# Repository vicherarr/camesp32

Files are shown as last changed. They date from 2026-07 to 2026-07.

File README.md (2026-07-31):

# 🛡️ ESP32-S3-CAM Moto Remote Vision & Security System

Un sistema de videovigilancia e IoT de bajo consumo compuesto por un **Firmware nativo en Rust para ESP32-S3-CAM** y una **Aplicación Móvil Android nativa en Kotlin con Jetpack Compose**.

---

## 📚 Documentación y Manuales Oficiales

Para consultar la información detallada del proyecto, accede a los manuales específicos ubicados en la carpeta [`docs/`](file:///home/victor/develop/iot/camesp32/docs):

- 📖 [**Manual del Dispositivo (Hardware, Leds, PIN 001989 y Operación)**](file:///home/victor/develop/iot/camesp32/docs/MANUAL_DISPOSITIVO.md)
- 📱 [**Manual de la Aplicación Android (Instalación, Pestañas y Transiciones)**](file:///home/victor/develop/iot/camesp32/docs/MANUAL_APP_ANDROID.md)
- 🏗️ [**Manual Técnico de Desarrollo (Desglose Completo de Código Rust y Kotlin)**](file:///home/victor/develop/iot/camesp32/docs/MANUAL_DESARROLLO_TECNICO.md)

---

## 📐 Arquitectura General del Sistema

El sistema utiliza un esquema **Híbrido de Bajo Consumo (BLE + WiFi Bajo Demanda)**:

```mermaid
graph TD
    A["Batería Moto / Powerbank 5V"] -->|5V / GND| B["ESP32-S3-CAM"]
    C["Radar RCWL-0516"] -->|GPIO14 ext0 wakeup| B

    subgraph ESP ["ESP32-S3 Firmware (Rust)"]
        B --> M{"¿Estado Alarma?"}
        M -->|Desarmado: Inicio/Ajustes| BLE["Bluetooth Low Energy (NimBLE)<br/>PIN 001989 · Bajo Consumo"]
        M -->|Desarmado: En Vivo/Galería| WIFI["WiFi Access Point (MIWIFI)<br/>Servidor HTTP REST"]
        M -->|Armado| DS["Deep Sleep (~µA)"]
        DS -->|Movimiento GPIO14| REC["Graba clip MJPEG-AVI a SD"]
        REC --> WIN["Ventana WiFi (~45s)<br/>para DESARMAR"]
        WIN --> DS
    end

    subgraph APP ["App Android CamEspDroid (Kotlin)"]
        K["App Android"] <-->|Control BLE / PIN 001989| BLE
        K <-->|Visión En Vivo & Galería AVI| WIFI
    end
```

---

## ⚡ Aspectos Clave del Sistema

1. **Bluetooth Low Energy (BLE) Always-On (Bajo Consumo):**
   - El canal principal de control en standby utiliza el stack NimBLE con emparejamiento por **PIN seguro `001989`** guardado en NVS (Bonding).
   - Permite armar/desarmar la alarma, conocer el estado del sensor y sincronizar la hora sin consumir batería.

2. **WiFi Bajo Demanda (Transición Implícita):**
   - El WiFi **solo se enciende cuando entras a la pestaña En Vivo o Galería** de la app.
   - La app muestra una **pantalla de progreso con cuenta atrás de 8 segundos** mientras realiza la vinculación local.
   - Al volver a la pestaña Inicio o Ajustes, el WiFi se apaga automáticamente y la radio vuelve a modo BLE.

3. **Optimizaciones de Memoria RAM:**
   - El firmware ejecuta `ble::shutdown()` liberando ~50 KB de RAM antes de levantar el WiFi para garantizar el funcionamiento fluido de la cámara y el servidor HTTP.

4. **Grabación de Vídeo MJPEG-AVI en SD:**
   - En modo armado, el radar despierta al procesador en milisegundos y graba clips `.AVI` completos con cabeceras RIFF y parcheado dinámico de FPS reales medidos.

5. **Reproductor AVI Integrado en la App Android:**
   - La app Android incluye un reproductor binario nativo escrito en Kotlin (`MjpegAviPlayer.kt`) que decodifica y reproduce los fotogramas del vídeo directamente sin depender de reproductores externos como VLC.

---

## 🚦 Leyenda de Colores del LED RGB (GPIO48)

| Estado | Color | Patrón | Significado |
| :--- | :--- | :--- | :--- |
| **Arrancando** | 🔴 rojo | fijo | Inicializando periféricos y hardware |
| **Standby Desarmado**| 🟢 verde | pulso | Esperando en bajo consumo |
| **Conectado BLE** | 🩵 cian | intercalado (1s) | App vinculada por Bluetooth |
| **Conectado WiFi** | 💛 amarillo | intercalado (1s) | Transmitiendo vídeo / galería por WiFi |
| **Ventana Armada** | 🔵 azul | parpadeo | Ventana abierta tras despertar para desarmar |
| **Grabando Vídeo** | 🟣 magenta | fijo | Grabando clip MJPEG-AVI por presencia |
| **Deep Sleep** | ⚫ apagado | — | Bajo consumo activo (~µA) |
| **Error Crítico** | 🔴 rojo | parpadeo rápido | Fallo de tarjeta MicroSD o cámara |

---

## ⚙️ Estructura del Repositorio

- [`esp32_cam_sec/`](file:///home/victor/develop/iot/camesp32/esp32_cam_sec): Proyecto completo de Firmware en Rust (ESP-IDF v5.2, NimBLE, RMT, VFS SDMMC).
- [`camesp32android/`](file:///home/victor/develop/iot/camesp32/camesp32android): Proyecto de la Aplicación Móvil Android en Kotlin (Jetpack Compose, MVVM, OkHttp, ConnectivityManager).
- [`carcasa_3d/`](file:///home/victor/develop/iot/camesp32/carcasa_3d): Modelos 3D y archivos CAD (.STEP, .STL, .FCStd) para la carcasa protectora.
- [`docs/`](file:///home/victor/develop/iot/camesp32/docs): Manuales completos del dispositivo, de la app y del desarrollo técnico.

---

## 📄 Licencia

Este proyecto está distribuido bajo la licencia MIT. Desarrollado para videovigilancia IoT de alto rendimiento y bajo consumo.

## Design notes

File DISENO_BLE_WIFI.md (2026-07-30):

# Diseño híbrido BLE + WiFi (cámara de moto)

> Caso de uso: cámara de seguridad para **moto**, se aparca lejos de casa (sin WiFi propia),
> uso en **proximidad**. Alimentación por powerbank. Ver decisiones tomadas al final.

## Principio
- **BLE = control** (siempre disponible en proximidad, ~1 mA en light-sleep): armar, desarmar,
  estado, poner la hora, encender/apagar WiFi.
- **WiFi AP = media bajo demanda** (en vivo, galería, clips): se enciende solo cuando se pide,
  y la app se conecta con **enlace local** (Android `WifiNetworkSpecifier`) para no cambiar la
  WiFi normal del móvil ni memorizar la red. Se apaga al salir.
- `alarm_armed` (NVS) solo decide **si el movimiento graba**. No hay reinicio al armar/desarmar
  (light-sleep conserva la RAM → cambio en vivo).

## Runtime del firmware (unificado)
```
BOOT → carga NVS (alarm_armed, ap_ssid/pass, pin) → arranca BLE (advertising + GATT)
       → configura PM (automatic light sleep) + wake por GPIO14 (movimiento)
LOOP (dirigido por eventos, light-sleep entre medias ~1mA):
  · Movimiento (GPIO14):
      - si armed: init cámara → grabar clip AVI a SD (con hora) → deinit cámara
      - si desarmado: solo marca estado/notifica
  · Comando BLE:
      - arm/disarm → set NVS alarm_armed (en vivo)
      - set-time(epoch) → fija RTC
      - wifi-on → levanta AP + servidor HTTP; notifica IP por BLE; lock anti-sleep
      - wifi-off (o timeout) → baja WiFi; vuelve a light-sleep
  · Durante grabación o WiFi-AP activo: PM lock (no light-sleep). Resto: light-sleep.
```

## GATT (servicio "Alarm Control")
- Service UUID: `a1b2c3d4-1111-4a5b-8c6d-000000000001` (provisional).
- **Estado** (read + notify): bytes `[armed, motion, wifi_on, ip(4)]`.
- **Comando** (write, con auth por PIN/bonding): 1 byte + args
  - `0x00` desarmar · `0x01` armar · `0x02` wifi-on · `0x03` wifi-off · `0x04` set-time (+8 bytes epoch ms)
- Nombre BLE: `CAMSEC-xxxx` (sufijo del MAC). Bonding con PIN.

## Ficheros y hora
- **FATFS LFN activado** (`CONFIG_FATFS_LONG_FILENAMES`) → nombres largos.
- Clip: `AAAAMMDD-HHMMSS.avi` si hay hora; si no, `CLIP0001.avi`.
- La hora la fija el móvil por BLE al conectar; el RTC la mantiene en light-sleep.

## App Android (pantallas)
- **Inicio**: estado por BLE (armado/desarmado, conectado, movimiento) + botón Armar/Desarmar
  (BLE). Indicadores BLE ● / WiFi ●.
- **En Vivo**: botón "encender cámara" → BLE wifi-on → la app abre el stream por la IP con
  enlace local. Solo con WiFi.
- **Galería**: media por WiFi bajo demanda. Fotos con Coil; **vídeos con reproductor MJPEG in-app**
  (parsea el AVI, extrae los JPEG `00dc`, play/pausa).
- **Ajustes**: emparejar BLE (elegir dispositivo + PIN), SSID/clave del AP de la placa, hora.
  Sin IP manual.
- Capa nueva: `BleManager` (escaneo/bond/notify/write) + uso de `WifiNetworkSpecifier` para la media.
- Permisos: `BLUETOOTH_SCAN`, `BLUETOOTH_CONNECT`, y los de WiFi/red ya presentes.

## Seguridad
- BLE: bonding con **PIN** (solo el móvil emparejado desarma).
- HTTP (media): añadir **auth básica** (usuario/clave) al servidor.

## Fases de implementación
1. **Firmware BLE core**: esp32-nimble, servicio GATT, arm/disarm/set-time; verificable con
   `bluetoothctl`. (Sin tocar aún el sleep.)
2. **Runtime unificado + PM light-sleep** (~1 mA) + WiFi AP on-demand + LFN/hora.
3. **App**: BLE + WifiNetworkSpecifier + reproductor de vídeo + rediseño de pantallas.
4. Auth HTTP + pulido + pruebas en placa.

## Decisiones tomadas (2026-07-30)
- WiFi: **AP bajo demanda + enlace local** (no STA; se aparca sin WiFi de casa).
- Vídeo: **reproductor in-app**.
- BLE: **emparejado con PIN**.
- Alimentación: powerbank (el ~1 mA del BLE en light-sleep es aceptable).

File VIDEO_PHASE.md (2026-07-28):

# Fase Futura (NO prioritaria): Grabación de Vídeo

> Análisis de viabilidad realizado el 2026-07-28 con datos reales de la webcam elegida
> (**Microdia / Sonix `0c45:2006`**, MJPEG). **Prioridad actual: FOTOS**, según lo ya definido.
> Este documento queda como referencia para cuando se aborde el vídeo.

## Resumen ejecutivo

Es viable grabar vídeo en la ESP32-S3-CAM, **pero solo como Motion-JPEG (MJPEG) en contenedor AVI**.
El ESP32-S3 **no tiene codificador de vídeo por hardware** (ni H.264/H.265; eso solo lo trae el
ESP32-P4), así que "vídeo" = secuencia de fotogramas JPEG guardados en un `.avi`.

**Objetivo realista y fiable: clips AVI-MJPEG de 640×480 a ~10 fps, grabados por evento de
movimiento** (no grabación continua). Sin audio (la cámara no tiene micrófono UAC).

## Datos medidos (frames MJPEG reales de la cámara)

| Resolución | Peso real por frame |
| :--- | :--- |
| 640×480 | **~52 KB** |
| 1280×720 | ~131 KB |

## Los dos cuellos de botella

### 1. Ancho de banda USB — Full-Speed
El USB del ESP32-S3 es **solo Full-Speed** (~780 KB/s útiles con la alt-setting isócrona de 800 B/frame).
- 640×480 → 780 ÷ 52 ≈ **15 fps máximo**.
- 1280×720 → ~6 fps (descartado para vídeo fluido).

### 2. Escritura en tarjeta SD — modo 1-bit (cuello más serio)
El firmware monta la SD en **1-bit** (`src/storage.rs`: solo D0, `CLK=39 / CMD=38 / D0=40`, `width=1`).
Escritura sostenida real ≈ **0.5–1.5 MB/s**.
- 640×480 @ 15 fps = 780 KB/s → **al límite** (riesgo de frames perdidos).
- 640×480 @ 10 fps = 520 KB/s → **seguro**.

Tamaño de archivo: 640×480 @ 10 fps ≈ **1.8 GB/hora**. FAT32 limita a **4 GB por archivo**
→ hay que **trocear en clips** (por tiempo o por evento de movimiento).

## Cómo implementarlo (cuando toque)

1. **Hilo de captura USB** (el mismo driver UVC de la fase de foto) volcando frames a un
   **ring-buffer en PSRAM** (~2–4 MB; la placa tiene PSRAM octal) para desacoplar captura de escritura.
2. **Hilo escritor** que vacía el ring-buffer a un archivo `.avi` MJPEG en la SD.
3. **Contenedor AVI**: cabecera RIFF + un chunk `00dc` por frame + índice `idx1` al final, con el
   valor de fps correcto para que se reproduzca bien (VLC/ffmpeg lo abren directo).
4. **Troceado de archivos** por límite de 4 GB / por duración / por evento.

## Mejoras de hardware si el vídeo pasa a ser importante

- **Cablear la SD en 4-bit** (si la placa expone D1–D3) → ~4× la velocidad de escritura, elimina el
  cuello de la SD.
- **Migrar a ESP32-P4**: USB **High-Speed** (480 Mbps) + **codificador H.264 por hardware** →
  vídeo HD real y comprimido. Es la vía si se quiere vídeo "en serio"; el S3 siempre estará
  limitado a MJPEG de baja resolución.

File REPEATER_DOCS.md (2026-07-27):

# 📡 ESP32 WiFi Repeater (Extensor de Rango NAT)

Este es un proyecto diseñado específicamente para la placa **NodeMCU ESP32 con módulo ESP32-WROOM-32D (30 pines)**. Su función principal es actuar como un repetidor WiFi (NAT Router) ultraestable para extender el rango de red de un router principal, permitiendo así que dispositivos como el ESP32-S3-CAM se conecten con una señal robusta.

---

## 🛠️ Especificaciones Técnicas

- **Microcontrolador**: ESP32 (Xtensa LX6 Dual-Core a 240 MHz).
- **Firmware**: Escrito en Rust nativo utilizando el framework `esp-idf` y la pila de red `lwIP`.
- **Topología**: 
  - **STA (Cliente)**: Se conecta a la red origen (`DIGIFIBRA-42H6`).
  - **AP (Punto de Acceso)**: Levanta una red extendida (`DIGIFIBRA-42H6_EXT`).
- **Enrutamiento (NAPT)**: Implementa Network Address and Port Translation (NAPT) a nivel de núcleo LwIP, asegurando alta velocidad y bajo consumo de CPU.

---

## ⚡ Optimizaciones de Estabilidad y Alcance

Para cumplir el objetivo de **máximo alcance y estabilidad absoluta**, se han aplicado los siguientes parámetros en la configuración profunda del chip (`sdkconfig.defaults`):

1. **Potencia de Transmisión (TX) al Máximo**: Se ha forzado a la antena a emitir a 20 dBm (el límite máximo físico del hardware ESP32) mediante `CONFIG_ESP_PHY_MAX_WIFI_TX_POWER=20`.
2. **Limitación de Velocidad (Baud Rate) para Ganar Sensibilidad**: Se ha activado `CONFIG_ESP_WIFI_TX_BAUD_RATE_1MBPS=y`. Al obligar a transmitir con esquemas de modulación más bajos y lentos (802.11b), la onda de radio penetra mejor los obstáculos y el router receptor puede "escucharla" a distancias donde el 802.11n se caería. (Ideal para máxima penetración en exteriores o paredes gruesas).
3. **Optimización de Memoria de Red LwIP**: Se han triplicado los buffers TCP (`TCPIP_RECVMBOX_SIZE`, `TCP_WND_DEFAULT`) y los hilos de red para asegurar que los paquetes de vídeo y peticiones de la cámara no se saturen, permitiendo hasta 4 dispositivos conectados simultáneamente de forma impecable.
4. **Ciclo de Vigilancia Activa (Watchdog)**: El hilo principal revisa periódicamente el enlace (cada 15s). Si la red principal (DIGIFIBRA) cae, se reconecta automáticamente sin intervención humana.

---

## 🚀 Compilación y Carga del Firmware

### Requisitos
El entorno asume que se cuenta con el toolchain de Rust para arquitecturas Xtensa (instalado vía `espup`).

### Comandos de Flasheo
```bash
# 1. Navegar al directorio del repetidor
cd esp32_repeater

# 2. Cargar variables del entorno (si aplica)
source ~/.cargo/env
source ~/export-esp.sh

# 3. Flashear la placa ESP32 por el puerto serial
cargo espflash flash --release --port /dev/ttyUSB0 --monitor
```
*(Nota: Las placas NodeMCU ESP32 suelen presentarse como `/dev/ttyUSB0` o `/dev/ttyUSB1`, a diferencia de la placa S3-CAM que es `ttyACM0`).*

---

## 🔌 Conexión y Uso

1. Conecta la placa ESP32 (NodeMCU) a un cargador de pared o PowerBank genérico de 5V por su puerto Micro-USB. 
2. Coloca la placa en un punto intermedio entre el router principal y la zona oscura donde irá la cámara.
3. El repetidor se conectará automáticamente.
4. Ve a la App de la cámara o a tu ordenador, y conéctate a la nueva red WiFi:
   - **SSID**: `DIGIFIBRA-42H6_EXT`
   - **Clave**: `Uyy4ZEPhXP`

## 💡 Indicador LED (GPIO2 / TX)
El repetidor cuenta con un sistema visual de diagnóstico a través del LED integrado en la placa (en muchas NodeMCU clónicas, este LED está conectado al puerto serie TX y parpadeará solo durante el arranque):
- **Parpadeo Durante el Arranque**: La placa está inicializándose y escribiendo logs (arranque, conexión y habilitación de NAPT).
- **LED Apagado Tras el Arranque**: En placas NodeMCU con LED en modo Active-HIGH o mapeado al puerto TX, el LED se apagará una vez que el sistema entra en modo de bajo consumo (sleep loop de 15s), lo cual **es completamente normal y significa que está funcionando con éxito**.
- **Canal Forzado**: Para evitar problemas de salto de canal en modo mixto, el repetidor **fuerza** que la red `DIGIFIBRA-42H6_EXT` se cree exactamente en el canal 4, coincidiendo con el canal del router original.

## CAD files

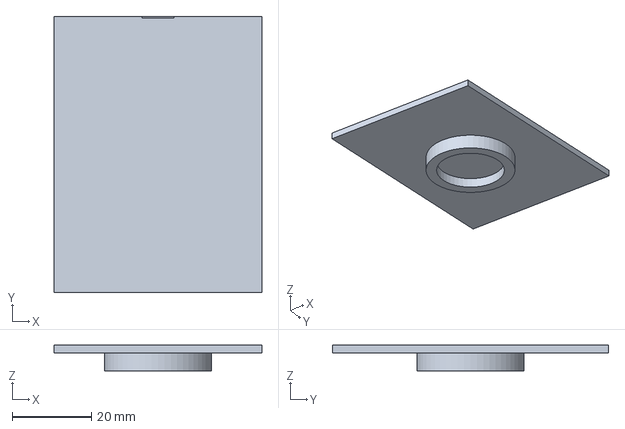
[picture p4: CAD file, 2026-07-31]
carcasa_3d/Tapa.3mf
52.4 x 69.6 x 6.50 mm

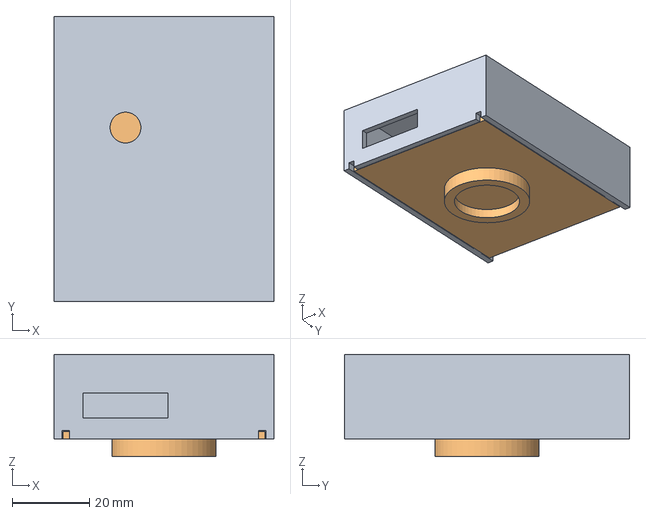
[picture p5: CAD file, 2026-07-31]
carcasa_3d/CarcasaCamMoto.step
57.0 x 74.0 x 26.5 mm

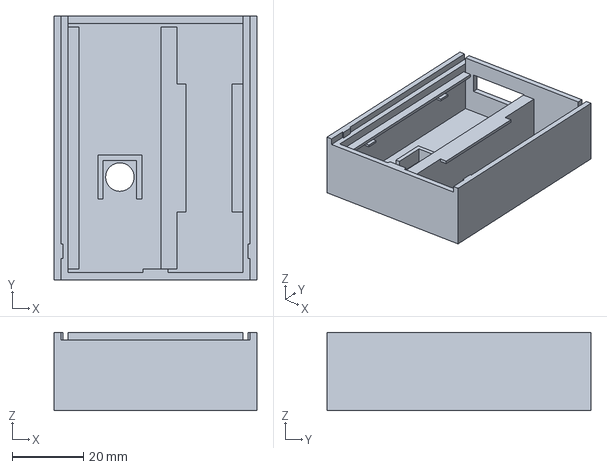
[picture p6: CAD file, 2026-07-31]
carcasa_3d/Base.3mf
57.0 x 74.0 x 22.0 mm

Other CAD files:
carcasa_3d/Base.stl
carcasa_3d/CarcasaCamMoto.3mf
carcasa_3d/CarcasaCamMoto.FCStd
carcasa_3d/Tapa.stl

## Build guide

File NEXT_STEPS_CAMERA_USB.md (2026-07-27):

# Fase 2: Implementación de Cámara USB OTG (UVC) en Rust y Mejoras de Red

## Estado Actual del Proyecto (Resolución de Problemas)
- **Modo Red**: Funciona en modo Cliente (STA) por defecto apuntando a la fibra del usuario. IP por defecto en App fijada a `192.168.1.143`.
- **Sensor de Movimiento**: Conectado al GPIO 13, funcionando en un bucle asíncrono no bloqueante. Se ha ajustado para capturar solo 1 frame por evento de movimiento (en vez de hacer ráfagas) para no saturar la tarjeta SD.
- **App Android**: 
  - La Galería SD está funcionando.
  - **BUG RESUELTO**: Se producían falsas caídas de WiFi en la App al abrir la Galería porque Coil abría demasiados sockets a la vez. Se ha solucionado implementando `ImageLoaderFactory` con `maxRequestsPerHost = 1`.
- **Tarjeta SD**: 
  - **MEJORA**: Se ha devuelto la velocidad de la tarjeta SD a 20MHz (por defecto) ya que la inestabilidad de red era puramente por la saturación de conexiones desde Android, logrando así lecturas más rápidas.
  - **BUG RESUELTO**: El endpoint web `/photos` ahora responde en streaming y está limitado a los 100 archivos más recientes para evitar agotar la RAM de la placa y colgar las peticiones (`timeout` en Android).

## Siguiente Tarea Pendiente
1. ~~**Poner IP Fija real en la placa**~~: **COMPLETADO**. La placa de la cámara ahora tiene asignada la IP estática `192.168.71.220` (gestionada mediante `ipaddr_addr` de la API en C `esp_netif_set_ip_info`).
2. ~~**Crear enrutador/repetidor NAT (esp32_repeater)**~~: **COMPLETADO**. Se ha implementado un repetidor ESP32 intermedio con NAPT usando LwIP (ip4_napt) que levanta la red extendida (`DIGIFIBRA-42H6_EXT` en `192.168.71.1`). 
    - **Solución NAPT**: Se ha configurado correctamente el *Port Forwarding* usando `ip_portmap_add`, asociándolo a la interfaz WAN (STA IP: `192.168.1.220`), permitiendo el acceso HTTP transparente desde la red principal. Todo el ruteo de extremo a extremo está operativo.
3. **Implementar el driver nativo UVC (USB Video Class)**: Para capturar los frames reales cuando se enchufe la cámara física USB OTG en los pines D+/D- del ESP32-S3.

### Diseño: Captura en Ráfaga y Envío a Telegram
Para evitar perder el momento crítico sin saturar la red, la lógica de movimiento operará así:
1. Al detectar movimiento, capturar una **ráfaga de 20 fotos** (1 foto cada ~0.5 segundos).
2. **Guardar cada foto** en la tarjeta SD de forma inmediata según se van tomando.
3. **Telegram Upload**: 
   - La **primera foto** de la ráfaga se debe enviar a Telegram **inmediatamente** en un hilo paralelo.
   - Las 19 fotos restantes se meterán en una **cola de subida en segundo plano** que las irá leyendo de la SD y enviando a Telegram poco a poco (una a una, con retraso) para no saturar la memoria RAM ni colgar la placa ESP32.
   - *Nota Técnica*: Habrá que añadir la inicialización de DNS (`esp_netif_set_dns_info`) en `wifi.rs` y un cliente HTTP/TLS (como `esp_idf_svc::http::client`) para atacar la API de `api.telegram.org`.

### Pasos a seguir para la Cámara Física (Para el Agente IA que retome esto)
1. **Quitar el Dummy JPEG**: En `esp32_cam_sec/src/camera.rs`, eliminar el array de bytes simulado (`dummy_jpeg`) dentro de `take_picture()`.
2. **Integrar esp-iot-solution**: Añadir dependencias en `build.rs` para linkear el componente C `usb_stream` (o usar FFI para importar los headers del driver de Espressif UVC).
3. **Driver USB Host**: Iniciar la negociación USB y los *endpoints* Isochronous/Bulk. El ESP32-S3 debe configurarse como USB Host.
4. **Captura de Fotogramas**: Modificar `main.rs` para implementar el bucle de ráfaga (20 fotos) e implementar la cola de envío en segundo plano para Telegram.
5. **Precaución**: Todo debe probarse de manera incremental conectando la cámara física y monitorizando los logs USB para evitar que un `panic!` rompa el bucle de red y el sensor.

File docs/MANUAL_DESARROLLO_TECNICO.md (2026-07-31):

# 🏗️ Manual Técnico Completo de Desarrollo: ESP32-S3-CAM & CamEspDroid

Este documento constituye la **guía técnica exhaustiva y exhaustivamente detallada** de la arquitectura, diseño de software, patrones de concurrencia y análisis código a código del proyecto **CamESP32 Moto Security System**.

El proyecto se divide en dos grandes subsistemas:
1. **Firmware Embebido para ESP32-S3:** Desarrollado en **Rust** sobre la capa `esp-idf-hal` / `esp-idf-svc` (ESP-IDF v5.2).
2. **Aplicación Móvil Android:** Desarrollada en **Kotlin** utilizando **Jetpack Compose**, **Coroutines**, **StateFlow** y **Clean Architecture (MVVM)**.

---

# 📚 SECCIÓN 1: INTRODUCCIÓN A RUST PARA PRINCIPIANTES EN EMBEBIDOS

Para comprender la parte del firmware, es esencial entender los conceptos fundamentales que hacen a **Rust** el lenguaje ideal para sistemas de misión crítica y de bajo consumo.

### 1.1 `no_std` frente a `std` en ESP32
En el desarrollo embebido tradicional en Rust se suele usar `#![no_std]` (sin la librería estándar, sin asignador dinámico de memoria por defecto). Sin embargo, en el ESP32-S3 con ESP-IDF utilizamos la **librería estándar de Rust (`std`)**, soportada gracias al sistema operativo en tiempo real **FreeRTOS** que subyace en ESP-IDF. Esto nos permite usar colecciones dinámicas (`Vec`, `VecDeque`), hilos de FreeRTOS (`std::thread`), primitivas de sincronización (`Mutex`) y gestión de memoria mediante punteros inteligentes (`Arc`).

### 1.2 El Sistema de Propiedad (Ownership) y Préstamo (Borrowing)
A diferencia de C o C++ donde la memoria se gestiona manualmente (`malloc`/`free`) arriesgándose a fugas de memoria o punteros colgados, Rust utiliza **Ownership**:
- Cada valor en Rust tiene un único "propietario" (una variable).
- Cuando la variable sale de su ámbito (scope), la memoria se libera automáticamente (RAII: *Resource Acquisition Is Initialization*).
- Si necesitas pasar datos sin transferir la propiedad, puedes hacer un **préstamo (Borrowing)**:
  - Referencia inmutable `&T`: Permite múltiples lectores a la vez.
  - Referencia mutable `&mut T`: Permite un solo escritor exclusivo a la vez.

### 1.3 Primitivas de Concurrencia Usadas en el Proyecto

#### `Arc<T>` (Atomically Reference Counted)
`Arc` es un puntero inteligente con contador de referencias atómico. Permite compartir la propiedad de un objeto entre múltiples hilos de ejecución de forma totalmente segura. Cuando el último `Arc` se destruye, el valor contenido se libera de la memoria.

#### `Mutex<T>` (Mutual Exclusion)
Un `Mutex` protege un dato mutable para que solo un hilo pueda acceder a él al mismo tiempo. En Rust, el datos vive **dentro** del Mutex (`Mutex<T>`). Para acceder a él, se llama a `.lock()`, lo que devuelve un `MutexGuard`. Mientras esa guardia existe, tienes acceso al dato. Al salir de scope, la guardia se destruye y el cerrojo se libera automáticamente.

#### `AtomicBool`, `AtomicU8`, `AtomicU64`
Son variables numéricas o booleanas cuya lectura y escritura se realiza directamente mediante instrucciones atómicas del procesador a nivel de hardware, sin necesidad de bloquear hilos con un `Mutex`. Usamos `Ordering::Relaxed` o `Ordering::SeqCst` para definir la consistencia de memoria.

#### `Option<T>` y `Result<T, E>`
Rust **no tiene valores nulos (`null`)**. 
- `Option<T>` representa un valor que puede existir (`Some(valor)`) o no (`None`).
- `Result<T, E>` se usa para manejo de errores. Puede ser una operación exitosa (`Ok(resultado)`) o un fallo (`Err(error)`). El operador `?` permite propagar un error hacia arriba de forma limpia.

#### FFI (Foreign Function Interface) y Bloques `unsafe`
El driver de la cámara GC0308 y las llamadas a bajo nivel de ESP-IDF están escritos en C. Rust se comunica con C mediante **FFI**. Debido a que Rust no puede garantizar lo que hace el código en C, las llamadas a funciones de C se envuelven en bloques **`unsafe { ... }`**, aislando la fragilidad del código de C del resto de la aplicación segura en Rust.

---

# 🦀 SECCIÓN 2: DESGLOSE COMPLETO DEL FIRMWARE ESP32-S3 (RUST)

El proyecto del firmware reside en el directorio `esp32_cam_sec/`.

```text
esp32_cam_sec/
├── Cargo.toml               # Dependencias de Rust y metadata de compilación
├── sdkconfig.defaults       # Configuración de FreeRTOS, PSRAM y Particiones
├── build.rs                 # Script de compilación y enlaces C con ESP-IDF
└── src/
    ├── main.rs              # Punto de entrada y máquina de estados principal
    ├── ble.rs               # Servidor GATT NimBLE, seguridad PIN 001989 y control
    ├── wifi.rs              # Gestión de AP/STA y ciclo de red WiFi
    ├── server.rs            # Servidor HTTP embebido y endpoints REST
    ├── camera.rs            # Driver DVP GC0308, FFI C y software JPEG (frame2jpg)
    ├── video.rs             # Grabador MJPEG-AVI en MicroSD (RIFF/AVI)
    ├── led.rs               # Driver RMT del LED RGB WS2812 (GPIO48)
    ├── storage.rs           # Montaje VFS FATFS para MicroSD (SDMMC 1-bit)
    ├── config.rs            # Persistencia de ajustes en NVS (Flash)
    ├── logbuf.rs            # Buffer circular de logs en RAM para diagnóstico
    └── discovery.rs         # Servidor UDP para autodescubrimiento en red local
```

---

## 2.1 `Cargo.toml` y `sdkconfig.defaults`

### `Cargo.toml`
Define las librerías de Rust (crates) clave:
- `esp-idf-sys`: Binding de bajo nivel con las cabeceras C de ESP-IDF.
- `esp-idf-hal`: Capa de abstracción de hardware (GPIO, RMT, SDMMC, I2C, SPI).
- `esp-idf-svc`: Servicios de ESP-IDF (WiFi, HTTP Server, NVS, SNTP).
- `esp32-nimble`: Crate optimizado de alto nivel para el stack de Bluetooth Low Energy (NimBLE).
- `anyhow`: Gestión simplificada de errores con contexto.
- `log`: Abstracción de registros de consola.

### `sdkconfig.defaults`
Configura los parámetros del SoC ESP32-S3:
- `CONFIG_ESP32S3_SPIRAM_SUPPORT=y`: Habilita los **8 MB de PSRAM octal**, imprescindible para alojar los buffers de fotogramas de la cámara.
- `CONFIG_PARTITION_TABLE_SINGLE_APP_LARGE=y`: Reserva una partición de **3.9 MB** para el ejecutable del firmware.
- `CONFIG_BT_NIMBLE_ENABLED=y`: Activa el stack NimBLE (ocupando mucho menos espacio en RAM que Bluedroid).

---

## 2.2 `src/main.rs` — Orquestador y Máquina de Estados

### Explicación del Código:
`main.rs` contiene la función principal `main()`. Al arrancar el chip:
1. **Inicializa parches de ESP-IDF:** `esp_idf_svc::sys::link_patches()`.
2. **Carga la configuración NVS:** Lee si el dispositivo estaba **Armado** o **Desarmado**.
3. **Causa de Despertar (`esp_sleep_get_wakeup_cause`):**
   - Si despertó por `ESP_SLEEP_WAKEUP_EXT0` (pin `GPIO14` del radar), significa que se ha detectado movimiento estando armado.
4. **Instanciación del LED RGB (`src/led.rs`):** Arranca el driver RMT en `GPIO48` y pone el color inicial a 🔴 **Rojo (Booting)**.
5. **Inicialización de Almacenamiento y Cámara:** Monta la MicroSD (`src/storage.rs`) y la cámara DVP (`src/camera.rs`).
6. **Bucle de Control / Lógica de Estados:**

```rust
// Fragmento simplificado del flujo principal en main.rs
let mut ble_control = BleControl::start(initial_armed);
let mut wifi_session: Option<(EspWifi, EspHttpServer)> = None;

loop {
    // 1. Procesar comandos recibidos por BLE (Armar, Desarmar, Encender WiFi, Hora)
    if let Some(cmd) = ble_control.take_command() {
        match cmd {
            CMD_ARM => { config.set_armed(true); enter_deep_sleep(); },
            CMD_DISARM => { config.set_armed(false); },
            CMD_WIFI_ON => { 
                // Apagar BLE para liberar ~50KB RAM antes de encender WiFi
                drop(ble_control);
                ble::shutdown();
                wifi_session = Some(start_wifi_and_http());
            },
            ...
        }
    }
    ...
}
```

---

## 2.3 `src/ble.rs` — Servidor GATT NimBLE y Seguridad PIN 001989

### Explicación del Código:
Este módulo implementa el canal de control por Bluetooth Low Energy usando `esp32-nimble`.

#### Estructuras y Constantes:
- `SVC_UUID`: UUID de 128 bits que identifica el servicio de control de la alarma (`a1b2c3d4-1111-4a5b-8c6d-000000000001`).
- `STATE_UUID`: Característica de lectura y notificación (`NOTIFY`) que envía el estado comprimido de la cámara `[armed, motion, wifi_on]`.
- `CMD_UUID`: Característica de escritura (`WRITE`) donde la app Android envía los códigos de comando (`0x00` Desarmar, `0x01` Armar, `0x02` WiFi ON, `0x03` WiFi OFF, `0x04` Poner hora).

#### Seguridad por Passkey (PIN 001989):
```rust
let mut security = device.security();
security.set_auth(esp32_nimble::enums::AuthReq::Bond | esp32_nimble::enums::AuthReq::Mitm);
security.set_io_cap(esp32_nimble::enums::SecurityIOCap::DisplayOnly);
security.set_passkey(1989); // PIN estático de emparejamiento (001989)
```
Al requerir `Bond` y `Mitm` con `DisplayOnly`, Android obliga al usuario a introducir la clave `001989`. El vínculo cifrado se almacena en la memoria NVS del ESP32-S3.

#### Optimización de RAM (`pub fn shutdown()`):
El ESP32-S3 comparte la radio entre Bluetooth y WiFi. Mantener ambos activos consume más de 100 KB de RAM. Cuando la app solicita encender el WiFi (`CMD_WIFI_ON`), el firmware ejecuta `ble::shutdown()`, invocando `BLEDevice::deinit_full()`. Esto **destruye el stack Bluetooth y libera ~50 KB de RAM**, asegurando que el servidor HTTP y la cámara tengan memoria suficiente para los buffers de fotogramas.

---

## 2.4 `src/wifi.rs` y `src/server.rs` — WiFi y Servidor HTTP REST

### `src/wifi.rs`
Inicializa el driver de WiFi en modo **Access Point (AP)** con SSID `MIWIFI` y clave `moto1112` usando la pila TCP/IP LwIP de ESP-IDF.

### `src/server.rs`
Levanta un servidor HTTP multihilo en el puerto 80 (`EspHttpServer`). Define los siguientes controladores de rutas:
- **`GET /photo`**: Captura un cuadro y lo devuelve como `image/jpeg`.
- **`GET /capture`**: Guarda una foto en la SD (`/sdcard/CAP_<ms>.JPG`).
- **`POST /arm` & `POST /disarm`**: Modifican el estado de la alarma en NVS.
- **`POST /wifi_off`**: Ordena el apagado del servidor HTTP y de la interfaz WiFi, provocando que el bucle principal de `main.rs` vuelva a arrancar el servidor BLE.
- **`GET /photos`**: Devuelve una lista JSON/HTML de los archivos multimedia en la SD.
- **`GET /file/*`**: Transmite archivos de la SD a la app mediante **streaming por bloques (Chunked Response)**, evitando cargar archivos enteros en la memoria RAM.

---

## 2.5 `src/camera.rs` — Driver DVP y Software JPEG (GC0308)

### Explicación del Código:
La cámara GC0308 no posee un codificador JPEG por hardware integrado (a diferencia de la OV2640).
1. El driver en C (`esp32-camera`) captura la imagen en formato plano de píxeles **RGB565** o **YUV422** a resolución VGA (640x480).
2. `src/camera.rs` utiliza FFI para llamar a la función C `frame2jpg()` de Espressif:

```rust
pub fn capture_jpeg(&self) -> Result<Vec<u8>> {
    let fb = unsafe { camera_sys::esp_camera_fb_get() };
    if fb.is_null() { anyhow::bail!("Error obteniendo frame buffer"); }
    
    let mut out_buf: *mut u8 = std::ptr::null_mut();
    let mut out_len: usize = 0;
    
    // Conversión de RGB565/YUV a JPEG por software
    let ok = unsafe {
        camera_sys::frame2jpg(fb, 80, &mut out_buf, &mut out_len)
    };
    
    // Copiamos el buffer a un Vec<u8> seguro de Rust y liberamos el buffer de C
    let jpeg_bytes = unsafe { std::slice::from_raw_parts(out_buf, out_len).to_vec() };
    unsafe {
        camera_sys::free(out_buf as *mut _);
        camera_sys::esp_camera_fb_return(fb);
    }
    Ok(jpeg_bytes)
}
```

---

## 2.6 `src/video.rs` — Grabador de Vídeo MJPEG en Contenedor AVI

### Explicación del Código:
Dado que el procesador genera tramas JPEG individuales mediante software, este módulo empaqueta los fotogramas en un archivo `.AVI` estándar que cualquier reproductor puede interpretar:

1. **Cabecera RIFF/AVI:** Escribe la estructura estándar de contenedores de vídeo (encabezados `hdrl`, `avih`, `strh`, `strf`).
2. **Cuerpo del Vídeo (`LIST movi`):** Por cada fotograma capturado, escribe la etiqueta de chunk `00dc` seguida del tamaño en bytes y del buffer JPEG.
3. **Tabla de Índices (`idx1`):** Al finalizar la grabación, añade al final del archivo una tabla con los offsets exactos de cada fotograma para permitir el rebobinado y avance rápido.
4. **Parcheado Dinámico de FPS:** Dado que la velocidad de codificación por software varía según la carga (~3-5 fps), al cerrar el archivo el grabador calcula los FPS reales medidos (`frames_totales / segundos_transcurridos`) y sobrescribe la cabecera `avih` para que el vídeo se reproduzca a la velocidad correcta sin acelerarse ni ralentizarse.

---

## 2.7 `src/led.rs` — Driver RMT para LED RGB WS2812 (GPIO48)

### Explicación del Código:
El LED inteligente WS2812 requiere una precisión temporal de **nanosegundos** para enviar los bits `0` y `1`:
- **Bit 0:** Pulso ALTO de ~350 ns + Pulso BAJO de ~800 ns.
- **Bit 1:** Pulso ALTO de ~700 ns + Pulso BAJO de ~600 ns.

El código utiliza el periférico **RMT (Remote Control Peripheral)** del ESP32-S3 a través del driver moderno `esp_idf_hal::rmt::TxRmtDriver` y `FixedLengthSignal`:

```rust
let color: u32 = ((g as u32) << 16) | ((r as u32) << 8) | (b as u32);
let mut signal = FixedLengthSignal::<24>::new();
for i in 0..24 {
    let bit_set = (color >> (23 - i)) & 1 != 0;
    let (high, low) = if bit_set { (t1h, t1l) } else { (t0h, t0l) };
    signal.set(i as usize, &(high, low))?;
}
self.tx.start_blocking(&signal)?;
```

---

# 🤖 SECCIÓN 3: DESGLOSE COMPLETO DE LA APP ANDROID (KOTLIN)

La aplicación reside en `camesp32android/` y sigue la arquitectura **Clean Architecture + MVVM + Jetpack Compose**.

```text
camesp32android/app/src/main/java/com/vicherarr/camespdroid/
├── MainActivity.kt           # Activity principal de Android
├── ble/
│   └── BleManager.kt         # Cliente GATT Bluetooth Low Energy (Android Bluetooth API)
├── network/
│   ├── WifiLink.kt           # Gestor de red local con NetworkRequest / ConnectivityManager
│   └── CameraRepository.kt   # Cliente REST HTTP con OkHttp 4
├── model/
│   └── MediaItem.kt          # Modelo de datos para fotos y vídeos SD
├── viewmodel/
│   └── MainViewModel.kt      # ViewModel centralizado y gestión de máquina de estados
└── ui/
    ├── MainScreen.kt         # Scaffold, barra de navegación y Dialog de carga (8s)
    ├── screens/
    │   ├── HomeScreen.kt     # Panel de armar/desarmar y leyenda de leds
    │   ├── LiveStreamScreen.kt # Visor en vivo por polling de snapshots
    │   ├── GalleryScreen.kt  # Grilla de archivos de la tarjeta SD
    │   └── SettingsScreen.kt # Pantalla de diagnósticos
    └── video/
        └── MjpegAviPlayer.kt # Reproductor nativo de vídeos MJPEG-AVI en Kotlin
```

---

## 3.1 `BleManager.kt` — Comunicación Bluetooth en Android

### Explicación del Código:
Encargado de escanear, conectar y comunicarse con el servidor GATT `CAMSEC`:
- **Escaneo por UUID:** Filtra los dispositivos Bluetooth para encontrar únicamente el servicio `SVC_UUID`.
- **Escritura de Comandos:** Envía bytes directos al característico `CMD_UUID` (`0x01` Armar, `0x02` WiFi ON, etc.).
- **Sincronización de Hora (`CMD_SET_TIME`):** Convierte el tiempo epoch actual del smartphone en ms a 8 bytes en formato **Little Endian** y los transmite a la cámara.
- **Suscripción a Notificaciones:** Escucha los cambios en `STATE_UUID` para actualizar en tiempo real los iconos de estado de la app.

---

## 3.2 `WifiLink.kt` — Vinculación Local de Red sin Perder Datos Móviles

### Explicación del Código:
Cuando un móvil Android se conecta al WiFi de la cámara (`MIWIFI`), al notar que dicho WiFi no posee acceso a Internet, Android tiende a ignorar esa conexión o desconectar los datos móviles.

`WifiLink.kt` soluciona esto usando la API `ConnectivityManager` con un `NetworkRequest`:

```kotlin
val request = NetworkRequest.Builder()
    .addTransportType(NetworkCapabilities.TRANSPORT_WIFI)
    .removeCapability(NetworkCapabilities.NET_CAPABILITY_INTERNET)
    .build()

connectivityManager.requestNetwork(request, object : ConnectivityManager.NetworkCallback() {
    override onAvailable(network: Network) {
        // Enlaza únicamente las peticiones de nuestra app a la red de la cámara
        connectivityManager.bindProcessToNetwork(network)
    }
})
```
Esto permite a la app comunicarse con la cámara por HTTP en `192.168.4.1` **sin interrumpir la conexión 4G/5G del resto del smartphone**.

---

## 3.3 `MainViewModel.kt` — Máquina de Estados y Prevención de Carreras

### Explicación del Código:
El `MainViewModel` mantiene el estado global en un `StateFlow<UiState>`.

#### Los Estados de Sesión (`MediaSession`):
- `None`: Conexión por BLE activa. WiFi apagado.
- `Opening`: En transición hacia WiFi (mostrando el diálogo con cuenta atrás de 8s).
- `Active`: WiFi enlazado y listo para En Vivo / Galería.
- `Closing`: En transición de vuelta a BLE.

#### Conmutación Implícita por Pestaña (`selectTab(index)`):
```kotlin
fun selectTab(index: Int) {
    _uiState.value = _uiState.value.copy(selectedTab = index)
    
    if (index == 1 || index == 2) { // En Vivo o Galería
        if (_uiState.value.mediaSession == MediaSession.None && _uiState.value.bleConnected) {
            openMediaSession()
        }
    } else if (index == 0 || index == 3) { // Inicio o Ajustes
        if (_uiState.value.mediaSession != MediaSession.None && _uiState.value.mediaSession != MediaSession.Closing) {
            closeMediaSession()
        }
    }
}
```

#### Manejo de Interrupciones y Evitación de Desincronización:
Si el usuario toca una pestaña mientras se está estableciendo la conexión, la corrutina `mediaJob` rastrea y cancela las tareas obsoletas para garantizar que la cámara y el móvil nunca queden colgados en estados inconsistentes.

---

## 3.4 `MainScreen.kt` — UI y Overlay Modal con Cuenta Atrás de 8s

### Explicación del Código:
Construido con Jetpack Compose. Renderiza el contenedor principal (`Scaffold`) y gestiona el **diálogo de carga modal ininterrumpible**:

```kotlin
var wifiCountdown by remember { mutableStateOf(8) }

LaunchedEffect(uiState.mediaSession) {
    if (uiState.mediaSession == MediaSession.Opening) {
        wifiCountdown = 8
        while (wifiCountdown > 0) {
            delay(1000)
            wifiCountdown--
        }
    }
}

if (uiState.mediaSession == MediaSession.Opening || uiState.mediaSession == MediaSession.Closing) {
    Dialog(onDismissRequest = { /* No cancelable */ }) {
        Surface(shape = RoundedCornerShape(16.dp), color = SurfaceDark) {
            Column(modifier = Modifier.padding(24.dp), horizontalAlignment = Alignment.CenterHorizontally) {
                CircularProgressIndicator(color = AccentCyan)
                Spacer(modifier = Modifier.height(16.dp))
                Text(
                    text = if (uiState.mediaSession == MediaSession.Opening) 
                        "Conectando WiFi de la cámara... ($wifiCountdown s)" 
                    else "Cerrando WiFi y volviendo a BLE...",
                    color = Color.White, fontWeight = FontWeight.SemiBold
                )
            }
        }
    }
}
```

---

## 3.5 `MjpegAviPlayer.kt` — Reproductor AVI Nativo en Kotlin

### Explicación del Código:
Android no incluye un decodificador nativo para archivos de vídeo `.AVI` codificados en formato MJPEG. Para evitar obligar al usuario a instalar reproductores de terceros (como VLC), se desarrolló `MjpegAviPlayer.kt`.

#### Algoritmo de Parsing Binario en Kotlin:
1. **Verificación de Cabecera:** Lee los primeros bytes buscando las marcas `RIFF` y `AVI `.
2. **Escaneo de Chunks `00dc`:** Recorre los bytes del archivo buscando la secuencia mágica `00dc` (que indica el inicio de un fotograma JPEG).
3. **Extracción y Decodificación:**
   - Extrae el bloque de bytes del JPEG entre `00dc` y el siguiente marcador.
   - Decodifica los bytes en un bitmap de Android usando `BitmapFactory.decodeByteArray()`.
4. **Bucle de Reproducción:** Un coroutine renderiza los bitmaps secuencialmente a la tasa de fotogramas adecuada en un canvas de Compose.

---

# 📝 SECCIÓN 4: CONCLUSIÓN Y MANTENIBILIDAD

El sistema **CamESP32 Moto Security System** representa un ejemplo avanzado de ingeniería de sistemas embebidos e IoT:
- Maximiza la autonomía mediante el apagado inteligente de radios y hardware.
- Protege la comunicación utilizando algoritmos de cifrado nativos y claves PIN persistentes en NVS.
- Proporciona una interfaz de usuario fluida, automatizada e intuitiva en Android sin requerir configuraciones complejas por parte del usuario final.

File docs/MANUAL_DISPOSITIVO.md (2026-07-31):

# 📖 Manual de Usuario y Operación del Dispositivo ESP32-S3-CAM

Manual oficial de instalación, configuración, operación y mantenimiento del dispositivo físico de videovigilancia **ESP32-S3-CAM Moto Security**.

---

## 📋 1. Descripción del Dispositivo

El **ESP32-S3-CAM Moto Security** es un sistema de videovigilancia IoT de ultra bajo consumo diseñado especialmente para vehículos (motocicletas, coches) o ubicaciones remotas. El dispositivo utiliza un procesador **ESP32-S3 Dual-Core**, una cámara integrada **GC0308** (o compatible DVP), un **LED de estado RGB (WS2812)**, un sensor de presencia por microondas **RCWL-0516 (Radar)** y una ranura para tarjetas **MicroSD**.

El sistema funciona con un esquema **Híbrido de Control BLE y WiFi Bajo Demanda**:
- **Consumo Mínimo / Espera (Bluetooth Low Energy - BLE):** El dispositivo permanece escuchando por BLE con un consumo insignificante. Desde la app puedes ver el estado, armar/desarmar la alarma o sincronizar la hora.
- **Transmisión de Vídeo / Galería (WiFi AP bajo demanda):** El WiFi **solo se enciende cuando entras a las pestañas En Vivo o Galería** de la app Android. Cuando vuelves a la pestaña de Inicio, el WiFi se apaga y vuelve al modo BLE de bajo consumo.
- **Modo Alarma Armada (Deep Sleep):** Si la alarma está armada, el ESP32-S3 se apaga en **Deep Sleep (~µA)**. Cuando el radar detecta movimiento, el procesador despierta en milisegundos, **graba un clip de vídeo MJPEG-AVI en la tarjeta MicroSD**, abre una pequeña ventana de conexión y vuelve a dormir si no hay intervención.

---

## 🔌 2. Esquema de Hardware y Pines (Pinout)

### 2.1 Tabla de Conexiones Principales

| Componente / Periférico | Pin ESP32-S3 | Tipo / Función | Notas e Instrucciones |
| :--- | :--- | :--- | :--- |
| **Alimentación (VCC)** | `5V` | Entrada 5V DC | Alimentado desde batería de moto mediante regulador 5V o USB-C |
| **Masa (GND)** | `GND` | Tierra Común | Conectar masa de alimentación y sensores a esta tierra |
| **Radar RCWL-0516 (OUT)** | `GPIO14` | Entrada Digital (`ext0_wakeup`) | Salida de 3.3V del radar al detectar presencia. ⚠️ **NO usar GPIO13** (conflicto con reloj de cámara). |
| **LED RGB WS2812** | `GPIO48` | Salida RMT (Data) | LED direccionable RGB integrado en la placa |
| **Tarjeta MicroSD (SDMMC)**| CLK=39, CMD=38, D0=40 | Bus SDMMC 1-Bit | Formato FAT32 (hasta 32GB recomendados) |
| **Cámara DVP GC0308** | Bus DVP de serie | Paralelo 8 bits | Cámara conectada por cable plano |

### 2.2 Diagrama de Cableado del Sensor Radar

```text
       ┌────────────────────────┐                   ┌────────────────────────┐
       │   Sensor Radar         │                   │     ESP32-S3-CAM       │
       │    RCWL-0516           │                   │                        │
       │  ┌──────────────────┐  │                   │  ┌──────────────────┐  │
       │  │       3V3        ├──┼─── (NC)           │  │       5V         ├──┼─── (Entrada VCC 5V)
       │  │       GND        ├──┼───────────────────┼──┤       GND        │  │
       │  │       OUT        ├──┼───────────────────┼──┤      GPIO14      │  │
       │  │       VIN        ├──┼───────────────────┼──┤       5V         │  │
       │  │       CDS        ├──┼─── (NC)           │  └──────────────────┘  │
       │  └──────────────────┘  │                   └────────────────────────┘
       └────────────────────────┘
```

---

## 🚦 3. Significado del LED de Estado RGB (GPIO48)

El LED RGB de la placa muestra de forma intuitiva qué está haciendo el dispositivo en todo momento:

| Color / Patrón | Estado del Sistema | Modo de Conexión | Significado / Acción |
| :--- | :--- | :--- | :--- |
| 🔴 **Rojo Fijo** | Inicializando | Ninguno | Arrancando hardware, NVS, cámara y SD. |
| 🟢 **Verde (Pulso)** | Alarma Desarmada | Ninguno | Sistema listo en standby. Esperando comandos por BLE. |
| 🩵 **Cian Intercalado (1s)**| Alarma Desarmada | **Conectado BLE** | App conectada mediante Bluetooth de bajo consumo. |
| 💛 **Amarillo Intercalado (1s)**| Modo Galería / Vivo | **Conectado WiFi** | El punto de acceso WiFi (`MIWIFI`) está activo y transmitiendo a la app. |
| 🔵 **Azul Parpadeante** | Ventana Armada | WiFi Activo breve | Alarma armada: despertó por movimiento o ventana abierta para desarmar. |
| 🟣 **Magenta Fijo** | Grabando | Ninguno | Escribiendo clip de vídeo MJPEG-AVI en la MicroSD por detección de presencia. |
| ⚫ **Apagado** | Deep Sleep | Ninguno | Alarma armada durmiendo (~µA). Despertará al detectar movimiento. |
| 🔴 **Rojo Parpadeo Rápido**| Error Crítico | Ninguno | Fallo al montar MicroSD o fallo al inicializar el sensor de cámara. |

---

## 🔒 4. Seguridad y Emparejamiento Bluetooth (PIN 001989)

Para evitar que extraños accedan a la cámara, el canal Bluetooth Low Energy utiliza **seguridad por clave PIN (Passkey Pairing) con Bonding guardado en NVS**:

- **Nombre del dispositivo BLE:** `CAMSEC`
- **PIN estático de emparejamiento:** `001989`
- **Comportamiento del PIN:**
  1. La primera vez que te conectas desde la app Android (o desde los ajustes Bluetooth de Android), el sistema operativo te pedirá vincular el dispositivo introduciendo el PIN.
  2. Escribe **`001989`**.
  3. El ESP32 guardará la clave de cifrado (bonding) en su memoria flash no volátil (NVS).
  4. Aunque resetees o quites la batería a la placa, **el emparejamiento se recuerda** y no volverá a pedir el PIN.

---

## ⚙️ 5. Modos de Funcionamiento y Operación

### 5.1 Modo Alarma Desarmada (Uso Diario / Monitoreo)
1. Conecta la alimentación al ESP32-S3. El LED se encenderá en 🔴 Rojo brevemente y cambiará a 🟢 Verde (pulso).
2. Abre la app **CamEspDroid** en tu smartphone.
3. El móvil se vinculará por BLE de forma transparente (LED cambiará a 🩵 Cian).
4. Cuando entres en la pestaña **En Vivo** o **Galería**, la app ordenará encender el WiFi. El LED pasará a 💛 Amarillo intercalado. Al salir a la pestaña **Inicio**, el WiFi se apagará automáticamente para ahorrar batería.

### 5.2 Modo Alarma Armada (Vigilancia / Aparcamiento)
1. En la pestaña **Inicio** de la app Android, pulsa el botón **ARMAR ALARMA**.
2. La placa guardará el estado en NVS y el LED se apagará (⚫ **Deep Sleep**).
3. Si alguien pasa delante del radar de la moto:
   - El sensor `GPIO14` despierta al procesador en milisegundos.
   - El LED se enciende en 🟣 **Magenta** y graba inmediatamente un clip `.AVI` en la MicroSD (aprox. 10 segundos).
   - A continuación, el LED parpadeará en 🔵 **Azul** abriendo una ventana de WiFi durante unos 45 segundos por si el propietario desea desarmar la alarma desde la app.
   - Si no se recibe orden de desarmar, la placa se vuelve a apagar en ⚫ **Deep Sleep**.

---

## 🛠️ 6. Mantenimiento y Solución de Problemas

### 🛠️ La cámara parpadea en Rojo Rápido
- **Causa:** La tarjeta MicroSD no está insertada, está llena o el formato no es FAT32.
- **Solución:** Extrae la tarjeta MicroSD, formatéala en FAT32 en tu PC e insértala firmemente antes de encender la placa.

### 🛠️ La app no se conecta al Bluetooth
- **Causa:** El Bluetooth del smartphone está desactivado o la placa está en Deep Sleep (Armada).
- **Solución:** Verifica que el Bluetooth del móvil esté encendido. Si la alarma estaba armada, pasa la mano por delante del radar para despertar la placa y abrir la ventana de conexión.

### 🛠️ Olvidé el PIN de emparejamiento
- El PIN por defecto del sistema es siempre **`001989`** (o `1989` según el diálogo de Android). Viene preconfigurado en el firmware.

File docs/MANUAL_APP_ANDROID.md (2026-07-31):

# 📱 Manual de Usuario - Aplicación Android CamEspDroid

Manual del usuario de la aplicación nativa para Android **CamEspDroid**, diseñada para el control remoto y visualización de la cámara de seguridad **ESP32-S3-CAM Moto Security**.

---

## 🚀 1. Instalación y Primeros Pasos

### 1.1 Requisitos Mínimos
- Smartphone con **Android 8.0 (API level 26)** o superior.
- **Bluetooth 4.2 / 5.0+** y radio **WiFi 2.4 GHz**.
- Permisos concedidos: *Dispositivos cercanos (Bluetooth)*, *Ubicación* (en Android 11 y anteriores para escaneo BLE) y *WiFi*.

### 1.2 Primera Vinculación Bluetooth (PIN 001989)
1. Abre la aplicación **CamEspDroid**.
2. Al iniciar por primera vez, Android solicitará permiso para buscar y conectarse a dispositivos cercanos. Acepta los permisos.
3. En la pestaña **Inicio**, la app buscará automáticamente el dispositivo `CAMSEC`.
4. El sistema Android mostrará un diálogo emergente pidiendo el PIN de emparejamiento.
5. Introduce la clave: **`001989`** (o `1989`).
6. Una vez emparejado, la aplicación recordará el vínculo permanentemente. Ya no volverás a ver este diálogo aunque reinicies la cámara o la app.

---

## 📱 2. Estructura de la Aplicación y Pestañas

La aplicación cuenta con 4 pestañas en la barra de navegación inferior, diseñadas con un esquema **totalmente automático de conmutación de red**:

```text
 ┌─────────────────────────────────────────────────────────┐
 │                   CamEsp32 Moto  [🩵 CONECTADO BLE]      │
 ├─────────────────────────────────────────────────────────┤
 │                                                         │
 │                    CONTENIDO DE LA PESTAÑA              │
 │                                                         │
 ├─────────────────────────────────────────────────────────┤
 │  [🏠 Inicio]   [📹 En Vivo]   [🖼️ Galería]   [⚙️ Ajustes] │
 └─────────────────────────────────────────────────────────┘
```

---

## 🧭 3. Funcionamiento de las Pestañas

### 🏠 Pestaña 1: Inicio (Bajo Consumo por BLE)
- **Modo de Red:** Conexión **Bluetooth Low Energy (BLE)** activa. El WiFi de la cámara está **apagado** para no consumir batería.
- **Badge Superior:** Muestra `🩵 CONECTADO BLE`.
- **Botón Armar Alarma:** Cambia el modo de la cámara a **Armado (Deep Sleep)**. El dispositivo se apaga y pasa a vigilancia activa por radar.
- **Botón Desarmar Alarma:** En caso de estar armada y en ventana de recepción, desarma la alarma y la devuelve al estado normal.
- **Leyenda del LED RGB:** Muestra un resumen visual interactivo con los colores del LED de la placa para que conozcas su estado físico en todo momento.

---

### 📹 Pestaña 2: En Vivo (Visión en Tiempo Real por WiFi)
- **Transición Automática:** Al tocar esta pestaña, la app ordena por BLE a la cámara encender su punto de acceso WiFi (`MIWIFI`).
- **Diálogo de Progreso:** Aparece una ventana modal con una **cuenta atrás interactiva de 8 segundos** mientras tu smartphone se vincula a la red WiFi local de la cámara (`"Conectando WiFi de la cámara... (8 s)"`).
- **Visor de Imágenes:** Una vez conectado (`💛 CONECTADO WIFI`), la pantalla muestra la transmisión en tiempo real a través de snapshots continuos.
- **Botón Capturar Foto:** Toma una fotografía en alta resolución y la almacena directamente en la tarjeta MicroSD de la cámara.

---

### 🖼️ Pestaña 3: Galería (Explorador SD y Reproductor AVI Nativo)
- **Transición Automática:** Al igual que en *En Vivo*, al seleccionar esta pestaña la app garantiza la conexión WiFi con la cuenta atrás de 8 segundos si venías de la pestaña Inicio.
- **Grilla de Contenidos:** Muestra todas las fotos (`.JPG`) y los clips de vídeo (`.AVI`) almacenados en la tarjeta MicroSD del dispositivo con sus miniaturas.
- **Reproducción Integrada de Vídeos MJPEG-AVI:**
  - Al tocar un clip de vídeo de la lista, se abre un visor modal con un **reproductor AVI nativo integrado**.
  - **No necesitas instalar reproductores externos** como VLC o MX Player; la app decodifica y reproduce los fotogramas dinámicamente en pantalla.
- **Borrado Masivo:** Incluye un botón para vaciar la tarjeta MicroSD de forma rápida con confirmación de seguridad.

---

### ⚙️ Pestaña 4: Ajustes
- **Modo de Red:** Conexión por BLE de bajo consumo.
- Muestra diagnósticos de la señal Bluetooth (RSSI), la dirección MAC del dispositivo, parámetros de red y opción para re-sincronizar la hora de la cámara con la del smartphone.

---

## ⚡ 4. Transiciones Automáticas e Implícitas (BLE ↔ WiFi)

Para maximizar la duración de la batería de la moto y ofrecer una experiencia de usuario perfecta, **no necesitas pulsar botones para encender el WiFi ni conectar el Bluetooth**:

1. **Estar en Inicio o Ajustes** ➔ La app mantiene la conexión por **BLE** (consumo mínimo).
2. **Cambiar a En Vivo o Galería** ➔ La app envía el comando `CMD_WIFI_ON` por BLE, muestra la **pantalla de carga de 8 segundos** y enlaza la red de la cámara internamente sin quitar la conexión de datos móviles de tu teléfono.
3. **Volver a Inicio o Ajustes** ➔ La app envía el comando HTTP `/wifi_off` a la cámara. La cámara apaga su red WiFi, enciende su Bluetooth y tu móvil se reconecta a **BLE** en cuestión de un segundo.

---

## ❓ 5. Preguntas Frecuentes (FAQ)

### ¿Se desconecta el Internet de mi móvil cuando entro a En Vivo o Galería?
**No.** La aplicación utiliza la API avanzada de `ConnectivityManager` de Android para enlazar únicamente el tráfico de la cámara a la red local `MIWIFI`, manteniendo los datos móviles (4G/5G) de tu teléfono activos para WhatsApp, llamadas, etc.

### Me pide el PIN otra vez tras apagar la moto, ¿es normal?
**No.** Si introdujiste el PIN correcto **`001989`**, la clave se guarda permanentemente en la memoria del dispositivo y de Android. Si te lo vuelve a pedir, asegúrate de no haber borrado los dispositivos vinculados en los ajustes Bluetooth de tu teléfono.

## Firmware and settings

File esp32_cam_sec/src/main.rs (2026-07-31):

mod camera;
mod server;
mod storage;
mod wifi;
mod config;
mod discovery;
mod logbuf;
mod led;
mod video;
mod ble;

use esp_idf_hal::peripherals::Peripherals;
use esp_idf_hal::gpio::*;
use ::log::{info, error};
use std::thread;
use std::time::{Duration, Instant};
use esp_idf_svc::sys;
use std::sync::{Arc, atomic::{AtomicBool, Ordering}};
use esp_idf_svc::nvs::EspDefaultNvsPartition;

// --- Parámetros ---
/// Pin del sensor de microondas (RTC-capaz).
const MOTION_GPIO: i32 = 14;
/// Duración del clip de vídeo por evento de movimiento.
const CLIP_DURATION_SECS: u64 = 10;
/// Tras grabar, espera este tiempo de inactividad antes de permitir otro clip.
const RECORD_COOLDOWN_SECS: u64 = 3;
/// Resolución del clip (VGA por defecto).
const VIDEO_WIDTH: u32 = 640;
const VIDEO_HEIGHT: u32 = 480;
/// Duración máxima de una sesión WiFi de media antes de volver a BLE (seguridad).
const MAX_WIFI_SECS: u64 = 180;

/// Ajusta el reloj del sistema (RTC) a partir de un epoch en milisegundos (recibido por BLE).
fn set_system_time_ms(ms: u64) {
    let tv = esp_idf_svc::sys::timeval {
        tv_sec: (ms / 1000) as esp_idf_svc::sys::time_t,
        tv_usec: ((ms % 1000) * 1000) as esp_idf_svc::sys::suseconds_t,
    };
    unsafe { esp_idf_svc::sys::settimeofday(&tv, std::ptr::null()); }
    info!("Reloj ajustado por BLE a {} ms epoch", ms);
}

/// Muestra un estado del sistema en el LED (ignora si no hay LED).
fn show_led(status: &mut Option<led::StatusLed<'static>>, state: led::LedState, phase: bool, conn: led::ConnMode, show_conn: bool) {
    if let Some(s) = status.as_mut() {
        let _ = s.show(state, phase, conn, show_conn);
    }
}

fn main() -> anyhow::Result<()> {
    sys::link_patches();
    logbuf::init();
    info!("Arrancando ESP32-CAM (híbrido BLE control + WiFi media)...");

    let peripherals = Peripherals::take()?;

    let mut status = match led::StatusLed::new(peripherals.rmt.channel0, peripherals.pins.gpio48) {
        Ok(l) => Some(l),
        Err(e) => { error!("Status LED init failed (continuando): {}", e); None }
    };
    show_led(&mut status, led::LedState::Booting, true, led::ConnMode::None, false);

    let nvs_partition = EspDefaultNvsPartition::take()?;
    let (mut cfg, mut nvs_handle) = config::load_config(nvs_partition.clone());
    info!("Config: alarm_armed={}, mode={}", cfg.alarm_armed, cfg.mode);

    let motion_sensor = PinDriver::input(peripherals.pins.gpio14, Pull::Down)?;

    let sd = match storage::Storage::new() {
        Ok(s) => Some(s),
        Err(e) => { error!("Storage init failed (continuando sin SD): {}", e); None }
    };

    // BLE PRIMERO (antes de WiFi): si no, el controlador BT se queda sin RAM y crashea.
    // Option porque se DEINICIA al abrir una sesión WiFi (liberar RAM) y se recrea al cerrarla.
    let mut ble: Option<ble::BleControl> = Some(ble::BleControl::start(cfg.alarm_armed));

    // Cámara (una vez; se usa para grabar y para /photo cuando hay WiFi).
    let cam = camera::Camera::new().ok();
    let cam_ok = cam.as_ref().map(|c| c.is_real()).unwrap_or(false);

    let motion_state = Arc::new(AtomicBool::new(false));
    let camera_ready = Arc::new(AtomicBool::new(cam_ok));
    let armed_flag = Arc::new(AtomicBool::new(cfg.alarm_armed));

    let wifi_mode = if cfg.mode == "STA" { wifi::WifiMode::STA } else { wifi::WifiMode::AP };
    // Flag que la app pone por HTTP (POST /wifi_off) para cerrar la sesión y volver a BLE.
    let wifi_off_flag = Arc::new(AtomicBool::new(false));

    // ALTERNANCIA BLE <-> WiFi (un solo radio a la vez): por defecto BLE (control). Al pedir
    // media, se PAUSA BLE (antena libre) y se abre una sesión WiFi (AP + servidor HTTP); al
    // cerrarla (POST /wifi_off o timeout) se DEINICIA WiFi y se REANUDA BLE. Evita la
    // degradación por coexistencia y permite bajo consumo (solo un radio activo).
    let mut session: Option<(wifi::WifiManager<'static>, server::WebServer)> = None;
    let mut session_start = Instant::now();
    let mut last_record = Instant::now() - Duration::from_secs(RECORD_COOLDOWN_SECS + 1);
    let mut tick: u32 = 0;

    info!("Runtime híbrido listo (alternancia BLE/WiFi). armed={}, cámara={}", cfg.alarm_armed, cam_ok);

    loop {
        tick = tick.wrapping_add(1);
        let is_motion = motion_sensor.is_high();
        motion_state.store(is_motion, Ordering::Relaxed);

        if session.is_none() {
            // ===== MODO BLE (control) =====
            let mut open_wifi = false;
            if let Some(b) = ble.as_ref() {
                if let Some(ms) = b.take_set_time_ms() { set_system_time_ms(ms); }
                while let Some(cmd) = b.take_command() {
                    match cmd {
                        ble::CMD_ARM => {
                            armed_flag.store(true, Ordering::Relaxed); cfg.alarm_armed = true;
                            let _ = config::save_config(&mut nvs_handle, &cfg);
                            info!("BLE: ARMADO");
                        }
                        ble::CMD_DISARM => {
                            armed_flag.store(false, Ordering::Relaxed); cfg.alarm_armed = false;
                            let _ = config::save_config(&mut nvs_handle, &cfg);
                            info!("BLE: DESARMADO");
                        }
                        ble::CMD_WIFI_ON => open_wifi = true,
                        ble::CMD_WIFI_OFF => {} // ya estamos en BLE, sin sesión WiFi
                        other => info!("BLE: comando desconocido 0x{:02x}", other),
                    }
                }
                if !open_wifi {
                    b.update_state(armed_flag.load(Ordering::Relaxed), is_motion, false);
                }
            }
            if open_wifi {
                // Abrir sesión de media: DEINICIAR BLE (liberar RAM) y levantar AP + servidor.
                ble = None; // suelta el BleControl
                ble::shutdown(); // deinit del controlador BLE
                wifi_off_flag.store(false, Ordering::Relaxed);
                let modem = unsafe { esp_idf_hal::modem::Modem::steal() };
                match wifi::WifiManager::new(modem, wifi_mode.clone(), nvs_partition.clone()) {
                    Ok(w) => match server::WebServer::new(
                        motion_state.clone(), nvs_partition.clone(), cfg.mode.clone(),
                        camera_ready.clone(), armed_flag.clone(), wifi_off_flag.clone(),
                    ) {
                        Ok(s) => {
                            session = Some((w, s));
                            session_start = Instant::now();
                            info!("Sesión WiFi ABIERTA (BLE deinicializado).");
                        }
                        Err(e) => {
                            error!("Servidor HTTP falló: {}; vuelvo a BLE", e);
                            drop(w);
                            ble = Some(ble::BleControl::start(armed_flag.load(Ordering::Relaxed)));
                        }
                    },
                    Err(e) => {
                        error!("WiFi falló: {}; vuelvo a BLE", e);
                        ble = Some(ble::BleControl::start(armed_flag.load(Ordering::Relaxed)));
                    }
                }
            }
        } else {
            // ===== MODO WiFi (media) ===== BLE apagado; control por HTTP.
            if wifi_off_flag.load(Ordering::Relaxed) || session_start.elapsed().as_secs() > MAX_WIFI_SECS {
                session = None; // drop -> deinicia WiFi + servidor (libera el puerto 80)
                ble = Some(ble::BleControl::start(armed_flag.load(Ordering::Relaxed)));
                info!("Sesión WiFi CERRADA (BLE reanudado).");
            }
        }

        // ===== Grabación por movimiento (en ambos modos si está armado) =====
        let armed = armed_flag.load(Ordering::Relaxed);
        
        // El sensor PIR necesita unos 15 segundos tras el encendido para estabilizarse.
        // Si no, al reiniciar la placa (estando armada), grabaría falsos positivos en bucle.
        let warmup_ok = tick > 60; // 60 ticks * 250ms = 15 segundos aprox
        
        if armed && is_motion && warmup_ok && last_record.elapsed().as_secs() >= RECORD_COOLDOWN_SECS {
            show_led(&mut status, led::LedState::Recording, true, led::ConnMode::None, false);
            record_event_clip(cam.as_ref(), sd.as_ref(), ble.as_ref());
            last_record = Instant::now();
            // Eliminado el bucle bloqueante 'quiet' para permitir procesar comandos BLE 
            // y que el LED muestre el estado real sin quedarse "congelado".
        }

        // ===== LED =====
        let led_state = if armed { led::LedState::ArmedWindow } else { led::LedState::Disarmed };
        let conn_mode = if session.is_some() { led::ConnMode::Wifi } else if ble.as_ref().map_or(false, |b| b.is_connected()) { led::ConnMode::Ble } else { led::ConnMode::None };
        let show_conn = tick % 4 == 0;
        show_led(&mut status, led_state, tick % 2 == 0, conn_mode, show_conn);

        if tick % 40 == 0 {
            info!("modo={} armed={} motion={}", if session.is_some() { "WiFi" } else { "BLE" }, armed, is_motion);
        }

        thread::sleep(Duration::from_millis(250));
    }
}

/// Busca el siguiente índice de clip libre en la SD (los CLIPnnnn.avi existentes).
fn next_clip_index() -> u32 {
    let mut next = 0u32;
    if let Ok(entries) = std::fs::read_dir("/sdcard") {
        for e in entries.flatten() {
            let name = e.file_name().to_string_lossy().to_ascii_uppercase();
            if let Some(rest) = name.strip_prefix("CLIP") {
                let digits = rest.split('.').next().unwrap_or("");
                if let Ok(n) = digits.parse::<u32>() {
                    if n + 1 > next { next = n + 1; }
                }
            }
        }
    }
    next % 10000
}

/// Graba un clip AVI-MJPEG a la SD durante `CLIP_DURATION_SECS`.
fn record_event_clip(cam: Option<&camera::Camera>, sd: Option<&storage::Storage>, ble: Option<&ble::BleControl>) {
    let cam = match cam {
        Some(c) if c.is_real() => c,
        _ => { error!("Sin cámara real: no se graba el clip"); return; }
    };
    if sd.is_none() {
        error!("Sin SD montada: no se puede guardar el clip");
        return;
    }

    // Nombre con fecha-hora si el reloj está puesto (LFN); si no, índice corto de reserva.
    let path = match storage::now_stamp() {
        Some(ts) => format!("/sdcard/{}.avi", ts),
        None => format!("/sdcard/CLIP{:04}.avi", next_clip_index()),
    };

    let mut rec = match video::VideoRecorder::new(&path, VIDEO_WIDTH, VIDEO_HEIGHT, 3) {
        Ok(r) => r,
        Err(e) => { error!("No se pudo crear {}: {}", path, e); return; }
    };
    info!("Grabando clip {} durante {}s...", path, CLIP_DURATION_SECS);
    let t0 = Instant::now();
    while t0.elapsed().as_secs() < CLIP_DURATION_SECS {
        // Cortar la grabación si llega un DESARMAR por BLE (respuesta rápida al usuario).
        if ble.map_or(false, |b| b.has_pending(ble::CMD_DISARM)) {
            info!("DESARMAR pendiente: cierro el clip antes de tiempo");
            break;
        }
        if let Some(jpeg) = cam.take_picture() {
            if let Err(e) = rec.add_frame(&jpeg) {
                error!("Error escribiendo frame: {}", e);
                break;
            }
        }
    }
    let frames = rec.frame_count();
    match rec.finish() {
        Ok(_) => info!("Clip {} guardado ({} frames)", path, frames),
        Err(e) => error!("Error cerrando clip {}: {}", path, e),
    }
}
pub mod auth_test;

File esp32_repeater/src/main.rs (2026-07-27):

use esp_idf_sys::{self as sys, ip_napt_enable};
use esp_idf_svc::wifi::{EspWifi, ClientConfiguration, AccessPointConfiguration, Configuration, AuthMethod};
use esp_idf_svc::nvs::EspDefaultNvsPartition;
use esp_idf_svc::eventloop::EspSystemEventLoop;
use esp_idf_hal::peripherals::Peripherals;
use esp_idf_hal::gpio::PinDriver;
use log::{info, error, warn};
use std::thread;
use std::time::Duration;
use std::sync::Arc;
use std::sync::atomic::{AtomicU8, Ordering};
use esp_idf_sys::{esp_netif_get_handle_from_ifkey, esp_netif_get_ip_info, esp_netif_ip_info_t};

// LED States
const STATE_CONNECTING: u8 = 0; // Parpadeo medio (500ms)
const STATE_CONNECTED: u8 = 1;  // Luz fija ON
const STATE_ERROR: u8 = 2;      // Parpadeo muy rápido (100ms)

fn main() -> anyhow::Result<()> {
    // Patches for ESP-IDF
    sys::link_patches();
    esp_idf_svc::log::EspLogger::initialize_default();

    info!("--------------------------------------------------");
    info!("Starting ESP32 WiFi Repeater (NAT) Extender");
    info!("Optimized for Stability and Maximum Range");
    info!("--------------------------------------------------");

    let peripherals = Peripherals::take()?;
    let sys_loop = EspSystemEventLoop::take()?;
    let nvs = EspDefaultNvsPartition::take()?;

    // Configure Built-in LED on GPIO2
    let mut led = PinDriver::output(peripherals.pins.gpio2)?;
    let led_state = Arc::new(AtomicU8::new(STATE_CONNECTING));
    let led_state_clone = led_state.clone();

    // LED controller thread
    thread::spawn(move || {
        let mut on = false;
        loop {
            match led_state_clone.load(Ordering::Relaxed) {
                STATE_CONNECTING => {
                    let _ = led.set_level(on.into());
                    on = !on;
                    thread::sleep(Duration::from_millis(500));
                },
                STATE_CONNECTED => {
                    let _ = led.set_high(); // Active-HIGH: high means ON
                    thread::sleep(Duration::from_millis(500)); // Sleep to not hog CPU, state won't change often
                },
                STATE_ERROR => {
                    let _ = led.set_level(on.into());
                    on = !on;
                    thread::sleep(Duration::from_millis(100));
                },
                _ => {
                    let _ = led.set_low(); // Active-HIGH: low means OFF
                    thread::sleep(Duration::from_millis(500));
                }
            }
        }
    });

    let mut wifi = EspWifi::new(
        peripherals.modem,
        sys_loop.clone(),
        Some(nvs)
    )?;

    // Extender Configuration
    // Target Network (Client STA)
    let sta_ssid = "DIGIFIBRA-42H6";
    let sta_pass = "Uyy4ZEPhXP";

    // Repeated Network (AP)
    let ap_ssid = "DIGIFIBRA-42H6_EXT";
    let ap_pass = "Uyy4ZEPhXP";

    info!("Configuring AP/STA Modes...");
    wifi.set_configuration(&Configuration::Mixed(
        ClientConfiguration {
            ssid: sta_ssid.try_into().unwrap(),
            password: sta_pass.try_into().unwrap(),
            auth_method: AuthMethod::WPA2Personal,
            ..Default::default()
        },
        AccessPointConfiguration {
            ssid: ap_ssid.try_into().unwrap(),
            password: ap_pass.try_into().unwrap(),
            auth_method: AuthMethod::WPA2Personal,
            channel: 4, // Explicitly match STA channel to prevent AP broadcast issues
            max_connections: 4, // Maximize memory stability
            ..Default::default()
        }
    ))?;

    // Configurar IP Fija (192.168.1.220) para el Repetidor en la red del router principal via C API
    info!("Configuring static IP for Repeater on main network (192.168.1.220)...");
    unsafe {
        let sta_netif = esp_idf_sys::esp_netif_get_handle_from_ifkey(b"WIFI_STA_DEF\0".as_ptr() as *const _);
        if !sta_netif.is_null() {
            esp_idf_sys::esp_netif_dhcpc_stop(sta_netif);
            let mut info: esp_idf_sys::esp_netif_ip_info_t = std::mem::zeroed();
            info.ip.addr = esp_idf_sys::ipaddr_addr(b"192.168.1.220\0".as_ptr() as *const _);
            info.netmask.addr = esp_idf_sys::ipaddr_addr(b"255.255.255.0\0".as_ptr() as *const _);
            info.gw.addr = esp_idf_sys::ipaddr_addr(b"192.168.1.1\0".as_ptr() as *const _);
            esp_idf_sys::esp_netif_set_ip_info(sta_netif, &info);
        }
    }

    info!("Starting WiFi...");
    wifi.start()?;
    
    // Connect to target network
    info!("Connecting to target network: {}...", sta_ssid);
    wifi.connect()?;

    let mut connected = false;
    for i in 0..60 {
        if wifi.is_connected().unwrap_or(false) {
            info!("Successfully connected to {}!", sta_ssid);
            connected = true;
            break;
        }
        thread::sleep(Duration::from_millis(500));
        if i % 10 == 0 {
            info!("Waiting for connection... {}s", i / 2);
        }
    }

    if !connected {
        error!("Could not connect to target network. Indicating error and rebooting.");
        led_state.store(STATE_ERROR, Ordering::Relaxed);
        thread::sleep(Duration::from_secs(5)); // Show error for 5 seconds
        unsafe { sys::esp_restart(); }
    }
    
    info!("Waiting for network initialization on STA interface...");
    thread::sleep(Duration::from_secs(3));

    // Enable NAPT on the AP interface
    unsafe {
        info!("Retrieving AP interface handle...");
        // In ESP-IDF, the default AP interface key is "WIFI_AP_DEF"
        let ap_netif = esp_netif_get_handle_from_ifkey(b"WIFI_AP_DEF\0".as_ptr() as *const _);
        
        if !ap_netif.is_null() {
            let mut ap_info: esp_netif_ip_info_t = std::mem::zeroed();
            esp_netif_get_ip_info(ap_netif, &mut ap_info);
            
            let ap_ip = ap_info.ip.addr;
            info!("AP IP Address Hex: {:X}", ap_ip);
            
            // Enable NAPT
            info!("Enabling NAPT (Network Address and Port Translation)...");
            ip_napt_enable(ap_ip, 1);
            info!("NAPT Enabled Successfully!");
            
            // Enable Port Forwarding to the Camera
            info!("Enabling Port Forwarding to camera at 192.168.71.220");
            // proto: 6 (TCP), maddr: STA IP, mport: 80, daddr: 192.168.71.220, dport: 80
            esp_idf_sys::ip_portmap_add(6, esp_idf_sys::ipaddr_addr(b"192.168.1.220\0".as_ptr() as *const _), 80, esp_idf_sys::ipaddr_addr(b"192.168.71.220\0".as_ptr() as *const _), 80);
        } else {
            error!("CRITICAL: Could not find AP netif! NAT will not work.");


            led_state.store(STATE_ERROR, Ordering::Relaxed);
        }
    }

    info!("Repeater is now running. Connect to '{}'", ap_ssid);
    led_state.store(STATE_CONNECTED, Ordering::Relaxed);
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

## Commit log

2026-07-26 Add ESP32-S3 firmware in Rust and Android Jetpack Compose app
    [partitions.csv]
2026-07-26 Add detailed sensor wiring diagram to README.md
2026-07-26 Synchronize BLE device names and enhance BLE scanning compatibility
2026-07-27 Implement non-blocking simulated camera capture
2026-07-27 Add roadmap for Phase 2: USB OTG Camera implementation
2026-07-27 Fix SDMMC pins for GOOUUU ESP32-S3-CAM
2026-07-27 Fix SDMMC slot config CD/WP pins to avoid init panic
2026-07-27 Optimize /photos to stream HTML and reduce dummy camera spam
2026-07-27 docs: Actualizar estado del proyecto con resolución de bugs de red y memoria SD
2026-07-27 feat: Add ESP32 WiFi Repeater based on lwIP NAPT for maximum range and stability
    [partitions.csv]
2026-07-27 chore: Remove accidental nested directory in esp32_repeater
    [partitions.csv]
2026-07-27 feat: Add LED indicator for WiFi repeater status (Connecting, Connected, Error)
    [main.rs]
2026-07-27 fix: Resolve Rust compilation type error for LED level
    [main.rs]
2026-07-27 fix: Resolve channel mismatch and add proper auth method for STA in Mixed Mode
    [main.rs]
2026-07-27 docs: Update LED color to red for NodeMCU AZ-Delivery
2026-07-27 fix: Invert LED logic for active-low red LED
    [main.rs]
2026-07-27 fix: Revert LED logic to active-high
    [main.rs]
2026-07-27 fix: explicit channel 4 for AP
    [main.rs]
2026-07-27 feat: Connect ESP32-S3-CAM to the new repeater network (DIGIFIBRA-42H6_EXT)
2026-07-27 docs: Update REPEATER_DOCS.md with LED behavior and fixed channel details
2026-07-27 Fix NAPT port forwarding and IP assignment in Camera and Repeater
    [partitions.csv]
2026-07-27 Update docs to reflect completed IP fixes and ESP32 Repeater NAPT architecture
2026-07-28 Add WiFi log readback (/logs) and reorder boot; video-phase notes
    - logbuf.rs: RAM ring-buffer logger (replaces EspLogger) that echoes to
    serial and keeps the last 400 lines for HTTP readback. This survives the
    loss of the USB-Serial-JTAG console once USB-OTG host mode takes the pins.
    - server.rs: add GET /logs endpoint returning the ring buffer as text.
    - main.rs: init the camera last (after WiFi + web server + discovery) so the
    network and /logs are up before the (future) USB host driver runs.
    - VIDEO_PHASE.md: feasibility notes for a future video-recording phase
    (MJPEG-AVI only; USB Full-Speed and 1-bit SD write limits).
    [main.rs]
2026-07-29 Cámara GC0308 de serie funcionando + LED de estado + fix pin sensor
    - Bindings de cámara: genera `camera_sys` desde el componente gestionado
    espressif/esp32-camera (arregla build roto). Elimina path de componente vacío.
    - camera.rs: detecta el sensor; el GC0308 (sin JPEG HW, PID 0x9b) se captura en
    RGB565 @ VGA y se convierte a JPEG por software (frame2jpg). Loguea el PID.
    - Sensor de movimiento GPIO13 -> GPIO14 (GPIO13 = PCLK de la cámara, conflicto HW).
    - LED RGB WS2812 de estado en GPIO48 (led.rs, RMT): azul/morado/cian arranque,
    verde = cámara OK, rojo = fallo, flash blanco al capturar.
    - Endpoint /photo (foto en vivo) que codifica a JPEG los sensores no-JPEG.
    - README: pinout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
    [camera.rs, main.rs]
2026-07-29 Fix galería SD y botón capturar de la app Android
    - server.rs: activa uri_match_wildcard (el handler /file/* daba 404 -> galería
    vacía en la app) y sube el stack del httpd a 8192 (buffer de /file en pila).
    - Añade endpoint GET /capture (captura + guarda en SD), que es el que usa el
    botón "capturar foto" de la app. Refactoriza la captura JPEG a capture_jpeg().
    - Nombres compatibles con FAT 8.3 (LFN off): CAPnnnnn.JPG y IMGnnnnn.jpg. El
    nombre largo anterior daba EINVAL (os error 22) al guardar en la SD.
    - README: documenta el endpoint /capture.
    [main.rs]
2026-07-29 Ráfaga de movimiento, borrar SD, En Vivo por snapshots y otros arreglos app/firmware
    Firmware (esp32_cam_sec):
    - Movimiento: ráfaga de 20 fotos, una cada ~0,5 s (cadencia objetivo, la captura
    del GC0308 ya consume ~0,5 s por el JPEG software). Nombres únicos IMGnnnnn.jpg.
    - Endpoint POST /deleteall (borra todas las fotos de la SD) + botón en el dashboard web.
    - Endpoint GET /capture (captura + guarda en SD) para el botón de la app.
    - Arreglo galería: uri_match_wildcard ON (/file/* daba 404) y stack httpd 8192.
    - Nombres SD compatibles con FAT 8.3 (evita EINVAL al guardar).
    App Android:
    - IP por defecto 192.168.1.220.
    - En Vivo: snapshots de /photo manteniendo el último frame (sin p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
    [main.rs]
2026-07-30 Rediseño bajo consumo: alarma ON/OFF, vídeo AVI, LED por estados, sin BLE→BLE híbrido (Fase 1)
    - Máquina de estados Modelo A: desarmado (WiFi always-on, no graba) vs armado
    (graba clip por movimiento + deep sleep). config.rs gana alarm_armed en NVS.
    - video.rs: grabador de clips MJPEG-AVI a la SD (header RIFF, idx1, fps reales).
    - led.rs: enum LedState con un color/patrón por estado (rojo/verde/azul/magenta/off).
    - server.rs: /arm, /disarm, armed en /info, Content-Type de vídeo.
    - wifi.rs: AP MIWIFI/moto1112. sdkconfig: consola por USB-JTAG, stack main 32KB.
    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
2026-07-30 Fase 2a: runtime híbrido unificado (BLE control + WiFi AP bajo demanda)
    - main.rs reescrito: un solo runtime. BLE siempre activo (control), WiFi AP
    encendido/apagado por comando BLE (CMD_WIFI_ON/OFF), y alarm_armed solo decide
    si el movimiento graba. Armar/desarmar en vivo por BLE (sin reiniciar).
    - ble.rs: cola FIFO de comandos (no se pierden en ráfaga) + has_pending() para
    cortar la grabación al recibir DESARMAR (respuesta rápida).
    - Quitado el descubrimiento UDP (redundante con BLE; su spawn de hilo crasheaba
    por memoria al coincidir con BLE+WiFi).
    - Validado en placa: arm/disarm/wifi-on/wifi-off aplican correctamente,
    coexistencia BLE+WiFi estable, sin crashes.
    Co-Authored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
    [main.rs]
2026-07-30 Fase 2b: nombres con fecha-hora (LFN + hora por BLE); WiFi/servidor persistentes
    - FATFS LFN activado (CONFIG_FATFS_LFN_HEAP): permite nombres largos. Clips/fotos
    se nombran AAAAMMDD-HHMMSS (storage::now_stamp) si el reloj está puesto; si no,
    índice corto de reserva. Adiós al límite 8.3.
    - Hora fijada por BLE (CMD_SET_TIME) via settimeofday; el RTC la mantiene.
    - server.rs: armed como Arc<AtomicBool> (estado vivo en /info); /capture con timestamp.
    - wifi.rs: radio_on/off (esp_wifi_start/stop) para media on-demand.
    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
2026-07-31 Fase 2c (parte 1): alternancia BLE<->WiFi (un solo radio a la vez)
    Resuelve la degradación por coexistencia y la presión de RAM: BLE y WiFi ya no
    están activos a la vez. Por defecto BLE (control); al pedir media (CMD_WIFI_ON) se
    DEINICIA BLE (BLEDevice::deinit_full, libera ~50 KB) y se abre una sesión WiFi
    (AP + servidor HTTP); al cerrarla (POST /wifi_off o timeout 180s) se deinicia WiFi
    y se recrea BLE (BLEDevice::init reinicia el controlador).
    - ble.rs: BleControl::start() llama a BLEDevice::init() (idempotente, permite
    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
2026-07-31 Fase 3: app Android para el modelo híbrido BLE (control) + WiFi (media)
    - ble/BleManager.kt (nuevo): escaneo/conexión a CAMSEC, estado por notify,
    comandos armar/desarmar/wifi-on/wifi-off/set-time (mismo contrato UUID que el firmware).
    - network/WifiLink.kt (nuevo): enlace local al AP con WifiNetworkSpecifier (Android 10+),
    sin cambiar la red del móvil; cliente OkHttp enrutado por esa Network.
    - network/CameraRepository.kt: cliente enrutado por el enlace; /wifi_off + descarga de clips.
    - ui/video/MjpegAviPlayer.kt (nuevo): parser AVI + reproductor MJPEG in-app (play/pausa/barra).
    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
2026-07-31 Fix sincronización y diagnósticos BLE en Android y optimización de notificaciones en ESP32
2026-07-31 Fix: borrado total SD (carpetas/timeout) + PIR warmup 15s + eliminado bucle bloqueante
    [main.rs]
2026-07-31 Fase 4: Seguridad total (Auth Básica HTTP y Emparejamiento BLE con PIN)
    [Base.3mf, Base.stl, CarcasaCamMoto.3mf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]
2026-07-31 Fix: Propiedades READ/WRITE en NimbleProperties para evitar filtrado en escáner BLE Android
2026-07-31 Fix: Configurado PIN BLE a 001989 y contraseña HTTP a 001989. Activada persistencia NVS para BLE.
2026-07-31 Feat: Parpadeo mixto en el LED (Cian para BLE, Amarillo para WiFi) y leyenda actualizada en la App
2026-07-31 Feat: Transiciones automáticas de conexión en la app (BLE <-> WiFi) al cambiar de pestaña y Progress Dialog
2026-07-31 Fix: Dialog de progreso ya no bloquea la barra de navegación para permitir cancelar cambiando de pestaña, y se cancelan los procesos en curso correctamente
2026-07-31 Revert: Restaurado Dialog modal ininterrumpible para proteger desincronización de estados
2026-07-31 Feat: Añadida cuenta atrás de 12 segundos al conectar al WiFi en el Dialog de progreso
2026-07-31 Update: Reducida cuenta atrás de conexión WiFi a 8 segundos
2026-07-31 Fix: Lanzar openMediaSession al conectar por BLE si la UI ya está en una pestaña de WiFi
2026-07-31 Docs: Añadida documentación completa del proyecto (Manual Dispositivo, Manual App Android y Manual Técnico de Desarrollo Rust/Kotlin) y README actualizado
